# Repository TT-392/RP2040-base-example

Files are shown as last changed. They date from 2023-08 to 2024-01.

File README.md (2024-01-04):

# RP2040-base-example
A simple dev board, created to test [RP2040-base](https://github.com/TT-392/RP2040-base)

Revision 0.9 was produced at jlcpcb. The rev number was bumped to 1.0 after the pcb was tested. There were no changes between rev 0.9 and 1.0. The production files in the "jlcpcb" folder are identical to the ones used to order the pcbs.

There seems to be one serious bug in the design, see "known issues" nr 1

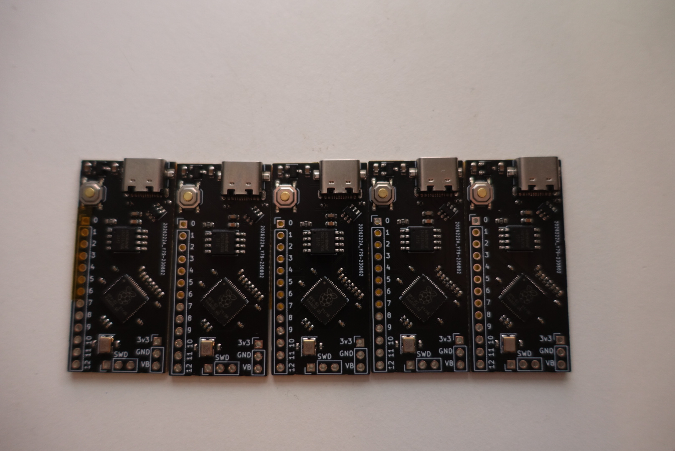
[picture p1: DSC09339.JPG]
5 pcbs of revision 0.9 with black solder mask

revision 0.9 of the pcb

# Tested functionality physical board rev 0.9 (identical to 1.0)
A sketch has been uploaded, which prints a string over cdc usb every second. This indicates working usb functionality, and working program memory.

After unplugging and plugging the board back in, the board doesn't seem to correctly start, see known issue nr 1.

# Notes
- jlcpcb has no basic part 27 ohm resistors, therefore, when ordering the test pcbs, the series termination resistors on the usb lines were replaced with 22 ohm ones (not too critical but not ideal)

# Known issues
1. There is something wrong with the chrystal setup, experiences the same issues as the adafruid boards mentioned in: https://github.com/raspberrypi/pico-sdk/pull/457. This can be fixed by setting PICO_XOSC_STARTUP_DELAY_MULTIPLIER to 64, like mentioned there.
2. No thought was given to which IO pins should be exposed, no analog pins have been exposed.
3. No debug LED.
4. ground plane on top layer wasn't taken into account when calculating trace with for usb line impedance matching (not too critical but not ideal)

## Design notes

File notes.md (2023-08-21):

# improvements
- No thought was given to which IO pins should be exposed, no analog pins have been exposed.
- No debug LED.
- ground plane on top layer wasn't taken into account when calculating trace with for usb line impedance matching (not too critical for usb 2.0, but not ideal)

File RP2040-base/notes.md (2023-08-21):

# Bugs
- Not compliant with jlcpcb design rules
- no explanation about the flash chip
- jlcpcb doesn't have basic 27 ohm resistors

# Improvements
- C4 could use a slightly better position (giving more space to GPIO0-7
- U2 could be closer to U1
- if chip were not at 45 degrees, that might have allowed for a smaller footprint
- rp2040 3d model, add pi logo
- jlcpcb part numbers

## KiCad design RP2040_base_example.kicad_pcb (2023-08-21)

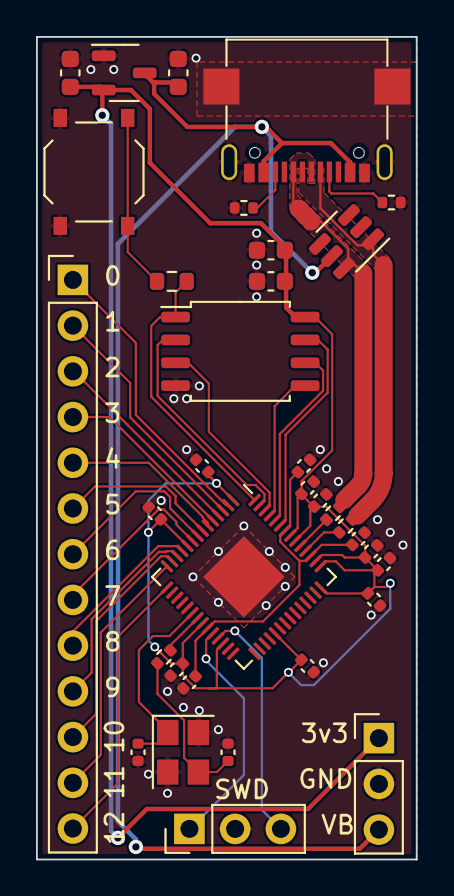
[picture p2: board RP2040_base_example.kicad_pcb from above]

Board: 2 copper layers, 21.1 x 45.7 mm, 34 parts (0 on the bottom side), 35 nets.

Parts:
C1, C2: 1u; C_0603_1608Metric
C3, C4, C5, C6, C7, C8, C9, C10, C11, C12: 100n; C_0402_1005Metric
C13, C14: 1u; C_0402_1005Metric
C15, C16: 30p; C_0402_1005Metric
C17: 100n; C_0603_1608Metric
C18: 10n; C_0603_1608Metric
J1: Conn_01x03; PinHeader_1x03_P2.54mm_Vertical
J2: Conn_01x13; PinHeader_1x13_P2.54mm_Vertical
J3: GT-USB-7047C
R1, R2: 5k1; R_0402_1005Metric
R3, R4: 27; R_0402_1005Metric
R5: 1k; R_0402_1005Metric
R6: 1k; R_0603_1608Metric
SW1: SW_Push; TS-1187A
SWD1: Conn_01x03; PinHeader_1x03_P2.54mm_Vertical
U1: XC6206P332MR; SOT-23-3_flipped_for_jlcpcb
U2: SRV05-4; SOT-23-6_flipped_for_jlcpcb
U3: RP2040; QFN-56-1EP_7x7mm_P0.4mm_EP3.2x3.2mm
U4: W25QXXXJV; SOIC-8_5.275x5.275mm_P1.27mm
Y1: X322512MSB4SI; YSX321SL, datasheet recommended measurements

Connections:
+3V3: C2.1, C5.1, C6.1, C7.1, C8.1, C9.1, C10.1, C11.1, C12.1, C14.1, C17.1, C18.1, J1.1, U1.2 (VO), U3.1 (IOVDD), U3.10 (IOVDD), U3.22 (IOVDD), U3.26 (RUN), U3.33 (IOVDD), U3.42 (IOVDD), U3.43 (ADC_AVDD), U3.44 (VREG_IN), U3.48 (USB_VDD), U3.49 (IOVDD), U4.8 (VCC)
/RP2040-base/1V1: C3.1, C4.1, C13.1, U3.23 (DVDD), U3.45 (VREG_VOUT), U3.50 (DVDD)
/RP2040-base/GPIO0: J2.1, U3.2 (GPIO0)
/RP2040-base/GPIO1: J2.2, U3.3 (GPIO1)
/RP2040-base/GPIO2: J2.3, U3.4 (GPIO2)
/RP2040-base/GPIO3: J2.4, U3.5 (GPIO3)
/RP2040-base/GPIO4: J2.5, U3.6 (GPIO4)
/RP2040-base/GPIO5: J2.6, U3.7 (GPIO5)
/RP2040-base/GPIO6: J2.7, U3.8 (GPIO6)
/RP2040-base/GPIO7: J2.8, U3.9 (GPIO7)
/RP2040-base/GPIO8: J2.9, U3.11 (GPIO8)
/RP2040-base/GPIO9: J2.10, U3.12 (GPIO9)
/RP2040-base/GPIO10: J2.11, U3.13 (GPIO10)
/RP2040-base/GPIO11: J2.12, U3.14 (GPIO11)
/RP2040-base/GPIO12: J2.13, U3.15 (GPIO12)
/RP2040-base/QSPI_SCLK: U3.52 (QSPI_SCLK), U4.6 (CLK)
/RP2040-base/QSPI_SD0: U3.53 (QSPI_SD0), U4.5 (DI(IO0))
/RP2040-base/QSPI_SD1: U3.55 (QSPI_SD1), U4.2 (DO(IO1))
/RP2040-base/QSPI_SD2: U3.54 (QSPI_SD2), U4.3 (IO2)
/RP2040-base/QSPI_SD3: U3.51 (QSPI_SD3), U4.7 (IO3)
/RP2040-base/QSPI_SS: R6.1, U3.56 (QSPI_SS), U4.1 (~CS)
/RP2040-base/SWCLK: SWD1.1, U3.24 (SWCLK)
/RP2040-base/SWD: SWD1.3, U3.25 (SWD)
/RP2040-base/USB_D+: J3.A6 (D+), J3.B6 (D+), R3.1, U2.6 (IO4)
/RP2040-base/USB_D-: J3.A7 (D-), J3.B7 (D-), R4.1, U2.1 (IO1)
/RP2040-base/XIN: C15.1, U3.20 (XIN), Y1.1
/RP2040-base/XOUT: R5.1, U3.21 (XOUT)
/RP2040-base/~USB_BOOT: R6.2, SW1.2
GND: C1.2, C2.2, C3.2, C4.2, C5.2, C6.2, C7.2, C8.2, C9.2, C10.2, C11.2, C12.2, C13.2, C14.2, C15.2, C16.2, C17.2, C18.2, J1.2, J3.A1 (GND), J3.A12 (GND), J3.B1 (GND), J3.B12 (GND), J3.S1 (SHIELD), R1.2, R2.2, SW1.1, SWD1.2, U1.1 (GND), U2.2 (VN), U2.3 (IO2), U2.4 (IO3), U3.19 (TESTEN), U3.57 (GND), U4.4 (GND), Y1.2, Y1.4
unnamed: C16.1, R5.2, Y1.3
unnamed: J3.A5 (CC1), R1.1
unnamed: J3.B5 (CC2), R2.1
unnamed: R4.2, U3.46 (USB_DM)
unnamed: R3.2, U3.47 (USB_DP)
VBUS: C1.1, J1.3, J3.A4 (VBUS), J3.A9 (VBUS), J3.B4 (VBUS), J3.B9 (VBUS), U1.3 (VI), U2.5 (VP)

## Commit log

2023-08-01 Improve ground path around voltage regulator
    [CPL-RP2040_base_example.csv, RP2040_base_example-CuBottom.gbr, RP2040_base_example-CuTop.gbr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]
2023-08-21 Bump version number
    [RP2040_base_example.kicad_pcb, RP2040_base_example.kicad_sch]
